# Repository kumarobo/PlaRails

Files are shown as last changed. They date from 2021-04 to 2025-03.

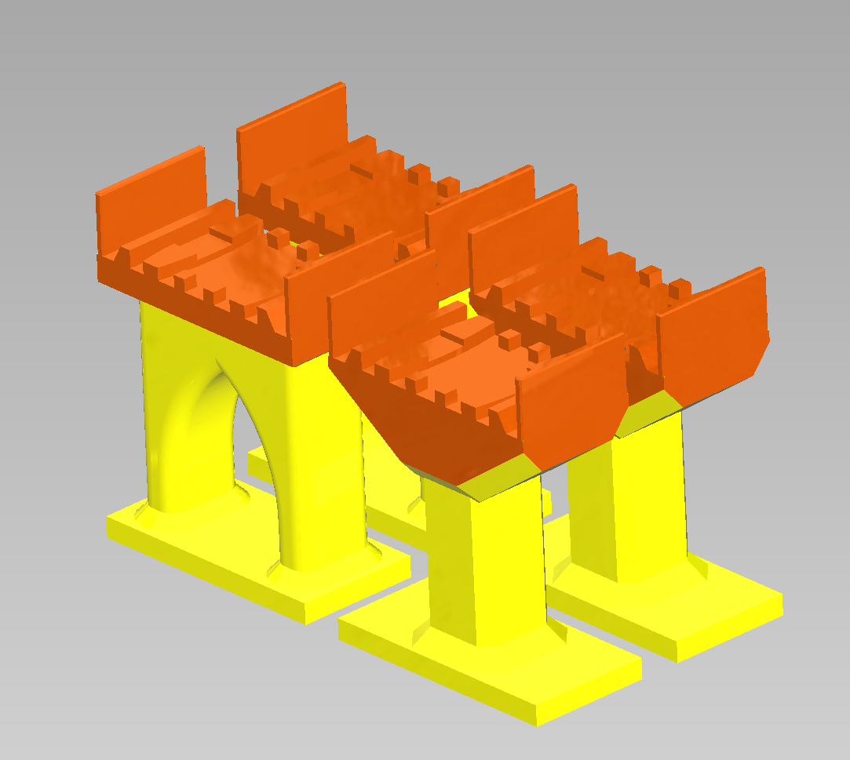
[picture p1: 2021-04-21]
ViaductPillar/vdpillar_printasm.png

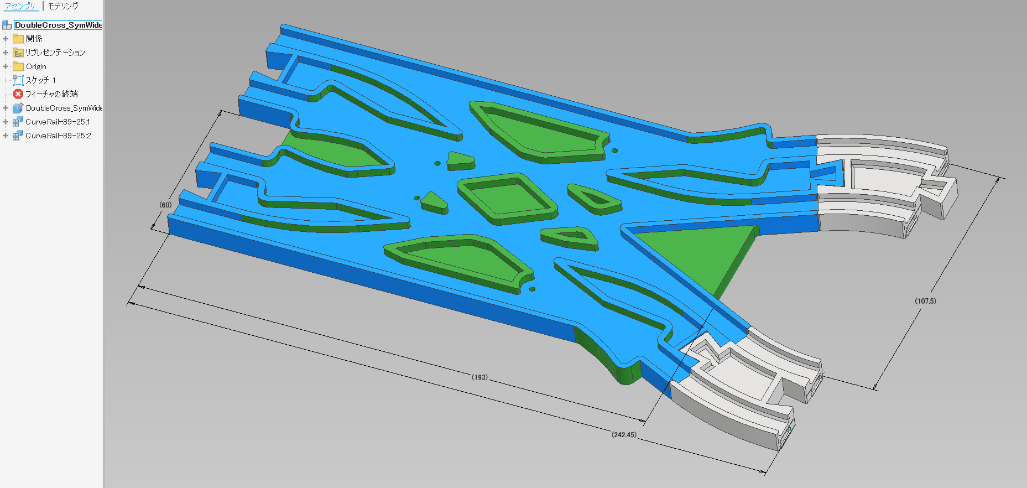
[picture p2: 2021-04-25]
DoubleCross/DoubleCross_SymWiden_testasm.png

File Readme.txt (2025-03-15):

プラレール　レール類設計データセット
熊谷正朗

０．はじめに

　この設計データはプラレールの特殊なポイントおよび高架橋線路を構成するための３次元設計データです。ふとしたきっかけ（忘れた；親戚からお下がりがたくさん届いて、子供らのレールレイアウトのバリエーションが増えたのが主因だと思う）から、突然試作を始めたものです。Twitterで関心を頂いたこと、および、形状構成の事例としての観点から、その設計データを公開することとしました。

１．本データの使用上の注意（ライセンス的）

・まず第一にプラレールは株式会社タカラトミーの登録商標であり、同社の製品です。それゆえ本データの使用の前提には、同社の制約があり、同社が禁じたことは禁じられます。
・本データはas isで提供するものであって、サポートは保障しません。
・本データの利用は、利用者の責任によるものとします。本データの利用に伴うトラブルは利用者で解決し、熊谷は関与しません（成形品の角によるけがや法的問題など）。
・本データの直接的な利用（プリンタによる成形出力）は個人の責任の範囲とし、個人、仲間内の範囲を超えての頒布（販売）は禁じます。ただし、タカラトミー社から正式になんらかの許可を得た場合などはその限りではなく、その場合は確認の連絡を下さい。
・本データのアイデア的な再利用（設計データや寸法を直接的には利用しない）については、利用者に一任します。引用などの明記も不要です。ただし、熊谷まで責任、問い合わせ等が及ばないものとします。
・本データの学修・教育的な利用についても、個人、あるいは学校・団体などの範囲で、利用の責任者が管理できる範囲で利用者に一任します。

※平たく言えば、「手元のデータを公開します。好きにしてかまいませんが、タカラトミー社と熊谷に迷惑が及ばないようにしてください」

２．データの説明
２．１　データの説明

・本設計データは Autodesk社の3DCAD Inventor 2021～2025 Professional (教育向け)で設計されています。同ソフトをインストールしてあれば、そのまま開け、寸法調整、加工等ができると期待されます。設計時のバージョンより古いと開けず、より新しいと変換時に一部ファイルの関係性が崩れる可能性があります。Fusion360ではインポートできるようですが、(関係は深いとはいえ)Inventorの機能を様々につかっているため、どの程度再現できるかは不明です。なお、Inventor(教育向け)は学校関係者は無償で利用できる場合があります。詳しくは同社サイトをご覧下さい。
・3Dプリンタ等用のSTLファイルが用意されている場合があります。これらは主に当方で出力することを念頭にしており、XYZプリンティング社 daVinci Super・ABS樹脂で出力を確認しています(成型誤差は0.1mm程度)。経験からすると、daVinci Pro 1.0でも同等の形状精度が得られると考えられますが、主にポイント類は長さが200mmを超えているため、斜めにおいても入らない場合があります。プリンタの成型精度の誤差については、以下のように調整用のパラメータがあります。
・一部、BambuLab P1Sで出力しています。寸法、形状性能的に、このサイトのレールを印刷するのにベストな機体の一つです（ついに家にもプリンタ置いてしまった）。一部、以前のデータを出力して寸法調整は不要なことを確認しています。
・後のものではSTEP(stp)ファイルが主になっていますが、GitHubのプレビューで形状が確認できるようにSTLも出しています。
・レールの基本長 L=215mm および ジョイント部の寸法、レール断面形状は、家にあったレールから適宜実寸していますが、製品でも寸法にあるていどのばらつきがありました。調整する場合の調整箇所は後述します。
・出力例、組み立て例、設計の解説は
　　　https://togetter.com/li/1682126
　にまとめてあります。

２．２　設計方針とファイルの命名規則
・ある程度ファイルの共通性再利用性を考慮した構成。
・iPart, テーブルを利用した設計
・ファイル拡張子等
　　・ .ipt ：Inventorパーツファイル
　　・ .iam ：Inventorアセンブリファイル
　　・ .stl ：プリンタ用STLファイル（GitHubでプレビュー可能）
　　　　　　　基本的に、同名のiam(優先)もしくはiptファイルから出力
　　・ .stp ：プリンタ用STEPファイル
　　・ _C 　：アセンブリファイルの簡略化のためのシュリンクラップ、
　　　　　　　派生のファイル。
　　・ _S 　：プリント用のサポート材の設計ファイル
　　　　　　　（_Sと_Sなしをアセンブルする場合、_Sに本来の出力対象も
　　　　　　　　含んでいて、これをプリントすれば良い場合の両者がある）
　　・ _MIR ：ミラー（鏡像）の派生ファイル
　　・ printasm ：複数部品をまとめて印刷するためなどのアセンブリ
　　・ testprint, testasm：組み立て試験や印刷試験用のファイル
　　　　　　　　（たとえばポイントのバーの動作参考用、
　　　　　　　　　印刷する前のイメージ確認）
　　・ .ipt, .iam と同名のフォルダ：iPartなどの中間ファイル置き場
　　　　　　　Inventorで自動生成されるので直接は触らない
　　　　　　　（どこかのアセンブリなどで使ったときにテーブルで指定
　　　　　　　　したパラメータでインスタンスができる感じ）
　　・ .png ：参考までに形状を画像で保存したもの。
　　　　　　　_Table.png はiPartのテーブル（ファイル名と寸法の対応）

・基本形式
　　１．機能を得るための形状設計（ポイント形状等）
　　　　　※フォルダ名と同名の iptファイル
　　２．それを分割、ミラー
　　３．レールのジョイント部とともにアセンブル
　　４．継ぎ目消しのため、シュリンクラップして単一形状化
　　５．パーツによってはサポート材の設計追加
　　６．STL出力
　ので、STLファイルと同名のiam (なければipt)から順次、要素を
　たどるとわかりやすい。

・出力の想定
　　・FDM形式の３Ｄプリンタでの出力を想定して調整。
　　　　スライス0.2mm、線幅0.4mmで調整
　　・プリンタ側（スライサ側）のサポートは使用しないことを前提とし、
　　　必要なら設計側でサポート材も設計に入れる
　　　※サポート材の除去の手間など
　　　※部品の下部の斜め面はサポート不要にするため
　　・XYZPrinting社 daVinci superで検証。
　　　一部は daVinci Pro 1.0で出力。
　　・RealRailsはBambuLab P1S＋eSun PLA+で出力検証

３．現時点で含まれている設計

３．１　概要

・特殊長直線、特殊曲率カーブ
・片渡り、単線複線ポイント、Ｓ字カーブ
　および、高架橋側壁オプション
　　　※片渡りからの派生品
・ダブルクロス（シザースクロス）
　　　※複線レール幅、レール超
　　　※ななめに分岐する特殊形を含む
・引き上げ線ポイント
　　　※駅間隔で２：３の線路

・高架橋　橋脚
・単純スロープ（地上から橋脚１段分まで）
・ユニット式高架橋橋脚およびスロープユニット
・リアルクラスに適したリアルな分岐

３．２　説明

●基本ファイル
・root/PlaRails.ipj
　　Inventorのプロジェクトファイル
・root/GlobalParameter.ipt
　　設計全体に関わるパラメータを含む（後述）
　　多くの設計ファイルは直接的、間接的にこのファイルからパラメータ参照している。
・root/RailJoint(Male, Female)(_filled).ipt
　　連結部の形状のファイル。
　　カーブ以外の形状はこれを部品として組み込んで使用している。
　　レールは表面のみであるが、橋脚にはめ込む凹部構造が裏にあり、
　　サポート構造を合わせてプリントするので、あとでラジペンなどでむしる。
　　_filledはこの構造がなく、埋まっている。
・root/RailUnitBase.ipt
　　連結部の元ファイル。ここから一方を消して、上記連結形状になる。
　　そのため、修正するのであれば、このファイル。寸法はGlobalParameterで
　　規定しているものが多い。

・Common/RailJointRS.ipt
　　レールのジョイント部分の形状を定義したファイル（新版）
　　レールの端が浮かなくするためのタブがあるものがあるが、それはあとで切り捨てる。

●特殊長直線 StraightRail/
・StraightRail_i.iam, _C.ipt
　　連結部を引き延ばす方法で直線レールにしている。
　　iPart テーブルで寸法可変。
　　_i でテーブルを選んで、_CからSTLを出力。
　　M, Fはオスメス形状、数値は長さ。

●特殊曲線 CurveRail/
・CurveRail.ipt
　　表裏が欲しいために特殊な構造。
　　XYZPrintの「サポート：底辺」付けたときのブロック部がある。
　　iPartのテーブルで半径と中心角を指定できる。
　　STLファイルの寸法は、半径-中心角、215halfは215/2。

●ダブルクロス・シザースクロス　DoubleCross/
・はじまりのレール。
　それゆえ、設計は一番汚いので、整理された設計は 片渡りシリーズ Crossover参照
・ストレートなダブルクロスと、渡り線をそのまま直進する形式の
　ポイントを構成可能な派生品を組み合わせでつくる。

・DoubleCross.ipt
　ベースとなる設計。ここで線形をすべて決めている。
　直進型の1/4のパーツと、斜め型の1/4のパーツをiPartで生成している。
　※まず両者を含む形を作り、不要部をマスクして、マスクのオンオフで選択。
・DoubleCross_Straight.iam / _C.ipt
　一般的な複線の直進レール間のダブルクロス。
・DoubleCrossBar.ipt / _MIR.ipt / Pin.ipt / Bar_printasm.iam
　ポイントのトングにあたるバーの設計データ。
　左右はあるが、直進・斜めとも同じバーを使うように設計してある。
　Pinはバーの動作軸部品。
　printasmは使いそうな部品のまとめ印刷セット。
・DoubleCross_Rturn
　「仙台市地下鉄東西線八木山動物公園駅型ダブルクロス」
　駅のホームに行くところが斜め分岐。
　testasmに、特殊長直線・カーブとの組み合わせ図。
・DoubleCross_SymWiden
　Rturnを両側にして、かつ、特殊カーブと組み合わせて駅幅＝(1/2)Lにする例。
　※この設計法の特徴例示でプリント試作はしてない
・DoubleCross_DoubleSlant, DoubleCross_DoubleSlip
　どちらもダブルスリップ的形状。png参照。
　※この設計法の特徴例示でプリント試作はしてない

・DoubleCrossRail.iam / _C.ipt / TestAsm
　上記レール群の試作検討用。

・組み立て方：
　　Bar(_MIR)にBarPinを入れて、レール部分の穴に固定する。
　　使用ネジ：M2ナット、M2x8mmネジ
　　ネジを入れる前に、BarとPinが抵抗なく回るようにBarの穴を調整。
　　BarPinおよびレール側の穴をネジがスムーズに通る程度に調整。
　　※5mmリーマ加工／2mmリーマ加工

●片渡り クロスオーバー　シングルクロス　および高架化側壁　CrossOver/
・片渡りポイント
　および、このデータから派生した、単線複線ポイント　複線Ｓ字渡りカーブ
・レール設計としては最終で、設計方針は一番洗練されている。

・SingleCross.ipt
　基本の設計ファイル。形状はすべてここで規定。
　ベースとなるのは片渡りの半分を含む、単線複線型レール。

・SingleCross_PointHalf.ipt / _MIR.ipt
　SingleCrossのポイント側半分、およびそのミラー。
・SingleCross_CurveHalf.ipt / _MIR.ipt
　SingleCrossのカーブレール側半分、およびそのミラー。

・SingleCrossIA.iam / _C.ipt / _C_MIR.ipt
　PointHalf, CurveHalfを組み合わせて、iAssemblyによって
　　・片渡り、シングルクロス
　　・Ｓ字カーブ
　　・単線複線ポイント（ジョイントのオスメスで２種）
　をつくる。
　STLの生成には、まずSingleCrossIAのテーブルで一種を選択し、
　それを反映した _C.ipt もしくは _C_MIR.iptからSTLを出力する。
・SingleCrossBar.ipt / _MIR.ipt
　ポイントのトングに当たるバー。
　ピンはDoubleCrossなどのものを流用。

・SingleCrossIA_Cross(_MIR).stl
　片渡りポイント STL
・SingleCrossIA_Curve(_MIR).stl
　Ｓ字渡り STL
・SingleCrossIA_PointA(_MIR).stl
　単線複線ポイントA型 STL

・SingleCrossIA_MIR.iam
　IA.iamのミラーにあたるアセンブリ。STLはIA.iamだけでつくれるが、
　別のアセンブリに読み込みたい場合用。

・ポイントの組み立て方はDoubleCrossと同じ。

・RailVCoverST.ipt ST_S.ipt
　直線レールを高架橋レール相当にするための外付けオプション側壁。
　ST.iptが必要な形状を規定し、ST_S.iptではプリントするための
　自前設計のサポート材を含んだ形状。
　ST.iptのfxのLengthパラメータで全長が指定できる。
　　（標準はレール長－連結部長さ＝橋脚の幅、高架レールと同じ形状）
　はめ込んだ後、裏面のフックに必要なら適宜輪ゴムなど。

・RailVCoverCV.ipt CV_S.ipt
　同じく、単線複線ポイントのカーブ側の側壁。
　ポイントの凸部を収納する構造。
　※Ｓ字渡りにもそのまま使える。
　組み合わせ方はpointtestasm参照。

●引き上げ線ポイント PocketTrackPoint/
・PocketPoint_C.ipt、.stl
　　ポイントレール部分の最終形状。プリント用。
・PocketPoint.ipt
　　ポイントの機能形状部分を規定してあるパーツ。
　　寸法調整などはこのファイルで行う。
・PocketPointBar*.ipt
　　ポイントのトングにあたるバーの形状を規定。
　　BarPinはバーの回転軸にあたるピン
・pp_bar_printasm
　　バー類をまとめてプリントしやすくしたアセンブリ
・組み立て方：
　　BarにBarPinを入れて、レール部分の穴に固定する。
　　使用ネジ：M2ナット、M2x8mmネジ
　　ネジを入れる前に、BarとPinが抵抗なく回るようにBarの穴を調整。
　　BarPinおよびレール側の穴をネジがスムーズに通る程度に調整。
　　※5mmリーマ加工／2mmリーマ加工

●少しおしゃれな高架スロープセット SimpleSlope/
・ユニット式高架橋セットの前段階の試作品
・市販の高架橋直線レールを主に用い、それを乗せる短レール付きの
　橋脚部品の３点セット。
　この３個のセット＋高架直線レール２本の組でしか役に立たない。
・全体で直線レール 2+(3/4)の長さになる
・SlopeProfile.ipt
　　線路の側面の線形の設計。ラインは走行面を基準としている。
　　高架直線レールを斜めに使うことで、水平面内では短くなる(cosθ)
　　影響は、橋脚部品の長さで補填している。
　　基本的に、GlobalParameter由来の数値で設計。
・Slope_LowEnd.ipt / .iam / _C.ipt
　　床面→スロープとなる下部部品。
　　高架レールを接続するとわずかに、高架レールの側壁角が床に当たる。
・Slope_Middle.ipt / .iam / _C.ipt
　　中間部分。高さ的には高架の半分。
・Slope_HighEnd.ipt / .iam / _C.ipt
　　スロープ→水平となる上部部品。高さは高架１段分。
・Slope_testasm.iam
　　直線レールと組み合わせた組み立て図。

※試作品なので、オスメスは１方向のみ
※iamのRailJointMale/Femaleをコンポーネント変更すればよい

●ユニット式高架橋 ViaductPillarUnit/
・標準の高架橋の高さ(以下、H)の1/2を基準として、高架橋を構成するユニット。
・高架橋の脚部と、1/4長レールを含む高架橋のユニットからなり、標準市販品の高架レールと組み合わせて使う。
・FDM式プリンタでプリントすることを想定して、サポート材を最初から適した形で設計に組み入れてある。
・脚部ユニットは角が鋭く、ある程度丸めた方が良いが、斜め45度の面はFDMプリントのことを考慮した形なので、修正は要注意。

・ViaductPillarUnit.ipt
　　以下の高架ユニットの基本形状の設計ファイル。
　　これを一度分割して、適宜組み合わせることで、必要な形状をつくる。
　　意匠の修正はこのファイルで行えば良い。
・ViaductPillarUnit_S.ipt
　　高架ユニットのプリント用サポート材。
　　それらしい形を作り、最後の「シェル」で薄肉化している。
・ViaductPillarUnit.iam　_C.ipt
　　無印と_Sを組み合わせたもの。

・VPU_EdgeBottom.ipt, VPU_edgeTop.ipt, VPU_MiddleBottom.ipt, VPU_MiddleTop.ipt
　　ViaductPillarUnit.iptを、端部・中間部を下部・上部に分割した物。
　　これを組み合わせると単一線路の複数スパンの高架がつくれる。
・VPU_SupportSingle.ipt
　　ViaductPillarUnit_S.iptのサポートの端部を切り出してミラーして、１区間ようのサポート材としたもの。

・ViaductPillarUnitIC.ipt, IC_S.ipt
　　複線にするための、幅方向の連結ユニットおよびそのサポート材。
・VPU_IC_Bottom, Top, SingleSupport.ipt
　　下部、上部、サポート材

・ViaductPillar_SingleSpan.iam _C.ipt
　　脚ユニット：長さ1/4長、幅１線路用、高さ(1/2)H・1H
　　テーブルでサポートの有無も含めて、切り替えて、_Cから、STL出力。
・ViaductPillar_SingleSpan_C_1u.stl, 05u.stl
　　STLにしたファイル。

・ViaductPillar_SigleSpan_Doublelane.iam, _C.ipt
　　長さ1/4長、複線用の脚ユニット。
　　_C_05u.stl は(1/2)HのSTL（サポート込み）

・Viaduct_HorizontalSingle.ipt, .iam, _C.ipt
　　(1/4)Lの直線レール、側壁を含む、高架橋ユニット。高架直線・曲線レールと接続できる。
　　基本設計は下記VPUSlopeと共通。

●ユニット式高架橋 スロープユニットセット VPUSlope/
・ユニット式高架橋の上部構造として、水平→登り傾斜、傾斜延長、登り傾斜→水平、の３ユニット。
・傾斜の斜度などはSimpleSlopeと互換（SimpleSlopeがVPUSlopeのアイデア検証試作）
・高架直線レールと組み合わせた１スパンで(1/2)H上る

・Slope_Profile.ipt
　　傾斜および水平との遷移の形状の側面図。各ファイルの形状の基準。

・Slope_LowEnd.ipt, .iam, _C.ipt
　　床面→登り傾斜のユニット。
　　.ipt は基本構造、.iamでレール端部と高架ユニットの脚接続部を組み付けて、_C.iptでラップしてSTL出力。
　　基本的に上り部は、間に挟む高架直線レールが、上がオス(凸側)、下がメス(凹側)になるようにしている。
　　全体の極性は、傾斜の出入り部で変えられるようにしてあり、.iamにFM型(水平側メス)とMM型(水平側オス)がある。
　　それぞれSTLとpngがある。

・Slope_LowEndHi.ipt, .iam, _C.ipt
　　高架水平→上り傾斜のユニット。
　　LowEndと同様。

・Slope_Middle.ipt, .iam, _C.ipt
　　上り傾斜の中間ユニット。１個入れるごとに全体で(1/2)H高くなる。
　　登り部の極性は固定のため、このユニットは１種のみ。

・Slope_HighEnd.ipt, .iam, _C.ipt
　　上り傾斜→高架水平のユニット。
　　同様に、FF型(水平側メス)とFM型(水平側オス)がある。

・testasm.iam testasm2.iam
　　組み立て例

●ダブルスリップポイント DoubleSlip/
・基本構成 直線の半分 (1/2)L で、45度に交差するダブルスリップポイントレール。
・２本のバーの可動で直進第一方向、直進第２方向、および分岐ができる。
　　※バーの位置は３カ所、中間点はラッチする
・ポイント内にバーの連動機構を持っていて、バーは対称に動作する。
・組み立てには、M2x8のナベネジ(x9くらいほしい) ２本、M2x5の皿ネジ１本、M2ナット３個とABS接着が必要。
・2021 6/13 改訂：
　　当初は斜め渡りするために、長さを√2倍したHS型を用意していたが、左右の必要性
　　などを考慮して、ポイントそのものは H (＝1/2L）型のみとし、斜め渡りに対応する
　　長さの短いレールと、ダブルクロスにするためのクロスのレールを別途組み合わせる
　　こととした。
　　そのほか、細部の寸法の調整。

・組み立て手順
　　・レール中央部にGearCenterをはめ、回転したときに「ほどほどの抵抗」があり、中央でラッチするように調整する。
　　　調整は、たとえば、GearCenterの内側をカッターなどで少し削って整えるなど
　　　（プリント時に面を後退させすぎるとそもそもかすらない可能性あり）
　　　中央より時計回りは少し緩めに、反時計回りをそれより少し強めに、がよい。
　　・M2のナットをしっかり押し込んでおく、必要なら一度ネジを入れてしっかり締める。
　　・GearBarBaseを左右のポストにさして滑らかに回るように。
　　・DSHR_BarCoverを重ねてネジで締められること、GearCenterない場合にほどほど緩く回ることを確認。
　　　※ここがわりと微妙、ネジの長さがギリギリで。BarCover裏を削る必要があるかもしれない
　　・GearCenterを入れて中央にラッチし、GearBarBaseにうっすらある直線の模様が、
　　　バーが分岐するのに適した方向、をほぼ向くように、噛み合わせてはめる。
　　　※直線の模様は単なる今後の作業の目安で、必須ではない
　　・GearBarBaseに、DoubleSlipHR_BarをABS接着剤で接着する。
　　　このとき、ギア部のガタは、GearBarBaseを時計回りにしっかり回して寄せておく。
　　　※当然のように周囲の可動部にも付くと思うので、位置決めしたら、BaseとBarの組をすぐに外した方がよい。
　　・接着剤が固まった後、穴の内部などを調整の上、組み立て。
　　　問題なければ、一方を動かすともう一方が対称に動く。
　　　※Coverをつけないと中央の穴に引っかかる場合があるので注意。
　　・GearCenterCoverを皿ビスで留める。
・組み立て（簡易）：
　　・特に連動とか不要なら、部品を一通り組み立てて、「接着」せずに、単にバーだけ渋く回るように調整する。

・DoubleSlipHR.ipt, .iam, _C.ipt, .stl
　　ポイント設計本体(ipt, 半分の形状)、iptと連結部を組み立てたもの(.iam, _C.ipt)。
　　.iptのパラメータ、テーブルにより、直進部分の長さを変えられる。
　　　　StraightLength/2 ＝ (1/2)L, *sqrt(2) ＝渡りにする長さ
　　　　接尾 _Hは(1/2)Lを、_HSは(1/2)L*sqrt(2)を設定してある。
　　　　※変更は .iamで使っている .iptのテーブル部

・DoubleSlipHR_asmtest.iam
　　ポイント機構の組み立て図。
　　※各部品の機械的な連動までは入れていない

・DoubleSlipHR_printasm.iam, .stl (printbase.ipt含む)
　　レール本体以外の部品類を印刷するためにまとめたもの。
　　レール本体にブリムをつけて一緒に印刷することを想定して、ブリムよけのガードが含まれる。

・DoubleSlipHR_Bar.ipt, DSHR_BarCover.ipt
　　ポイントのバー部品。および、バーを上から押さえるカバー(一部レール要素)。
・GearBarBase(Gear20含む), GearCenter(Gear30含む), GearCenterCover.ipt
　　バーを動かすギア部品(一部走行面を含む)、中央のギア(バーの位置決めをするラッチ構造を持つ)、
　　同カバー(分岐時に走行する面)。

・CrossRail.ipt, .iam, _C, _C_DSS.stl
　　直角交差のレール。
　　DoubleSlipHR_C_H_Hと組み合わせると、駅幅のダブルクロスポイントができる。
　　交差が小さく、連結部が干渉するので、削る小細工をしている。

・/StraightRail/StraightRail_C_DSSMF.stl
　　DoubleSlipHR_C_H_Hと組み合わせると、駅幅の片渡りができる。
　　組み立て例はtogetterなど参照。

・RailJointShortMale/Female(_filled)(_ShortHead).ipt
　　レールの連結部、ただし、root/にあるものに比べて、部品の長さを限界まで短くした。
　　レール側に窪みが必要(DoubleSlipHR.iptの端部参照)
　　_filledは裏面の橋脚にはめる構造を埋めたもの
　　_ShortHeadは上記CrossRailとあわせて、走行面を確保するために先を削った形状。
　　　　（DoubleSlipHRはこの形状）

●Ｓ字シフトレール ShiftRail/
・複線などの線路間隔を変更するための、方向は変わらずに横にシフトするＳ字のレール
・現在のラインナップは、駅複線((1/2)L)を複線レール幅(60mm)と変換するためのレールで、
　その間隔の 1/2, 1/1, 3/2 の３種
　※1/2は２個対象に使うと幅が変換できる、1/1は片方のみ(複線幅広ポイントレールと同型)
　※3/2は複々線から拡げる(3/2, 1/2, 1/2, 3/2と使う)
・レール線形は簡易的なクロソイド曲線
・珍しく「表裏対応」型、FDMプリントのサポートの設計付き。

・ShiftRail.ipt
　　レールの設計本体。
　　作図は1/4のみで、ShiftRail.ipt でレールの1/2部分が完成する。
　　テーブルで寸法を切り替える。
　　パラメータ：
　　　　Length：進行方向の長さ　（線路仕様）
　　　　Shift：遷移幅　（線路仕様）
　　　　MinRadius：最小半径　　（調整項目）
　　　　CLength：曲線区間長さ　（調整項目）
　　　　NSection：クロソイド区間数（固定値）
　　　　CF：クロソイド化フラグ：1でクロソイド、0でただの円弧
　　　　SD：現時点で不要
　　　設定方法：
　　　　・LengthとShiftを欲しいレールの寸法で決定する
　　　　・スケッチ１を見ながら、MinRadiusがなるべく大きくなるように、
　　　　　曲線区間が作図範囲の概ね中央部にくるようにCLengthを調整。

・ShiftRail_TC.ipt, .iam, _C.ipt
　　レール形状に組み立てる。
　　_TCはiPartでなくするための中間派生ファイル、.iamで連結部含めて組み立て、
　　_C.ipt でレール形状は完成。サポート不要なら _CからSTLを出力。

・ShiftRail_S.ipt
　　ShiftRail_C.ipt にFDMプリント用のサポート材を付加。
　　サポートの条件は davinci superで出力するように調整してある。

・ShiftRail_S_*.stl
　　プリント用STL
　　　　12L_HDL12：長さ＝(1/2)L、シフト＝(駅幅(HL)－複線幅(D))×(1/2)
　　　　34L_HDL：　長さ＝(3/4)L、シフト＝(駅幅(HL)－複線幅(D))×(1/1)
　　　　1L_HDL32： 長さ＝(1/1)L、シフト＝(駅幅(HL)－複線幅(D))×(3/2)
　　　※12L_HDL12_C：12L_HDL12 のクロソイドではない円弧版、比較用
　　いずれも、ぎりぎり短くしてあるのでこれ以上短いのは曲率的に難しい

・RailJointDSMale/Female.ipt
　　このレール用の最短連結部パーツ。
　　両面レールに対応した形状。

●リアルなレール分岐 RealRails/
・組立には、Amazon等で売られているインサート ナット2mm外形3mm長さ3mmを使う。
　　※使用したのはuxcell ローレットM2x3, ASIN B0778FB9Y5
　　それ以外を使う場合は圧入穴の微調整がいる。

・RealRailsParameter.ipt
　　形状データは無く、このシリーズで使う数値パラメータを持つ。
・RR_SingleTurnout
　　直線－通常曲線の分岐。
　　_CA, _CBはレールそのものの形状、_SA_C, _SB_Cはプリント用のサポートを含む。
　　（スライスソフト側でサポート設定をしない）
　　Leverはトングレールおよびそのスライド部品。レール本体にバーを差し込んで、
　　対のトングレールを押し込んではめ込むことで一体化させる。
　　トングレールの一方（ボスがあるほう）にはナットをインサート。
　　ネジはM2x8の皿ビスが適合。
・RR_ThreeWay
　　三分岐。
　　添え字は上記の通り、ただし、トングレールは２セット有る。
　　スライド部品を両側から差し込み、数ミリ開いた位置が直進の状態になるので、
　　そこで直進側トング（まっすぐのもの）を挿す。穴が合わない場合はスライダを交換。
・SwitchLeverUnit
　　分岐を駆動するためのレバーユニット。転轍機。
　　上記分岐のスライド部品がでているところに、はめる。
　　下部ケースLowerCaseの四隅の穴の奥にナットをインサートしておく。
　　下部ケースLowerCaseにスライダSliderをはめる(接続ピンが連結形状側)。
　　そこにらせんローラ部品RollerにレバーLeverを圧入したものを付ける。
　　この段階で倒すとスライダが動く。
　　上部ケースをかぶせて、M2x12で締める。
　　レバーを真上付近にすると、スライダ＝分岐器のトングがフリーに動く。
　　そこから両方向に倒すと強制的にスライダが動く。　　

●高架橋脚 ViaductPillar/
・VDPillar_A, VDPillar_B, vppillar_printasm.stl
　　複線レール間隔にも対応した、高架レール向けの橋脚。橋脚に側壁が付いている。
・StandardPillarCover　　※iam, stlは４個まとめて印刷用
　　通常の橋脚に高架レールを乗せて出っ張った部分に、それらしいカバーを付ける。

●「大きな鉄橋」部品 TrussCC/
・思えば、もらってきた鉄橋でこの部品がないから、つくるか、とか
　思ったのがすべての始まりだった気がする。

●その他 Misc/
・AsterMale.ipt / AsterMale_?.stl
　　放射状になるレール。

３．３　設計全体を調整するパラメータ
● /GlobalParameter.ipt
・パラメータ(fxアイコン)に全体の設計を決定づけるパラメータがある。
・各ファイルは直接、間接にこれを引用しているので、ここを書き換えて更新すると、反映される。

●パラメータ一覧
・PrinterOffset
　　プリント時の補正値。プリンタ側で設計値よりも寸法が大きくなる場合
　　（幅が増える、穴が小さくなるなど）にこの数値で寸法を減らせる。
　　ジョイント部の寸法補正などに使われている。
・StraightLength
　　直線レールの長さ。
　　当方の実測で215mmとしてあるが、216mmという説もある。
・RailWidth
　　レール幅
・OuterWall
　　レールの壁部の外側＝レール幅のところ、の壁の幅
・InnerWall
　　同じく、内側の壁の幅
・InsideWidth
　　内側（車輪の走らない領域）の幅
・RailHeight
　　レール全体の厚さ
・RailDepth
　　レール上面から走行面までの深さ、言い換えれば走行面両側の壁の高さ
・ConnectorLength
　　レール連結部部品/RailJointの長さ。
　　この部品を使っているパーツは多いため、変更はかなり要注意。
・JointM?, JointF?
　　レール連結部の凹凸の形状を決める寸法。市販レールでもばらつきがあるため、
　　手元のレールとはまるようにそれらしく拾ってある。
・DoubelWidth
　　複線の間隔。これは60mmでコンセンサスがあるようだ。
・ViaductHeight
　　市販の橋脚の高さ。高架橋シリーズなどの寸法を規定している。
・SupportGap
　　自前のサポート部材があるときに、サポート部材と本体の隙間を規定。
　　FDMプリンタの一層分の隙間がよさそう（当方はすべて0.2mmスライス）。
　　この隙間で結合が弱くなることで、サポート部材をはがせる。
・SupportRib
　　サポート部材の壁の幅。FDMで１列分のフィラメント出力が出る程度。
　　当方は0.4mmのフィラメント出力で少し太めにしてある。（計算誤差対策）

４．まとめ
・とくにまとめはありません（文末表記）

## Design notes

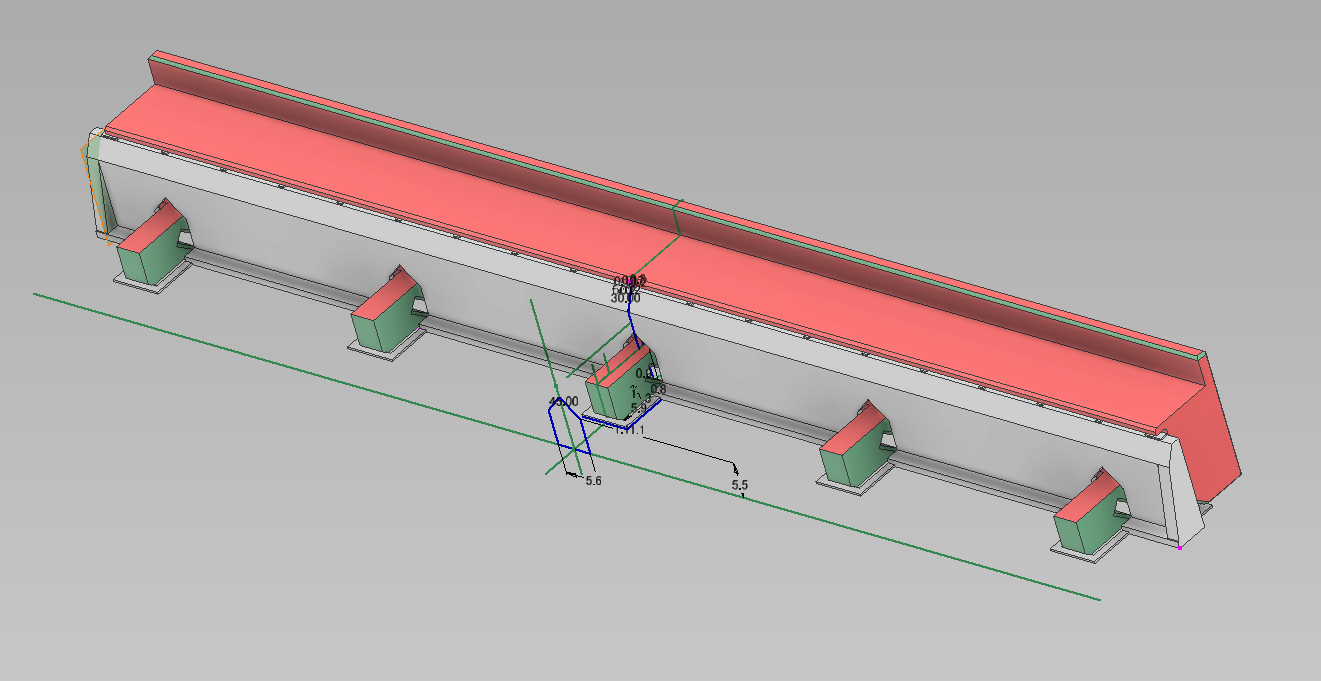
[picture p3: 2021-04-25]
Crossover/RailVCoverST_S.png

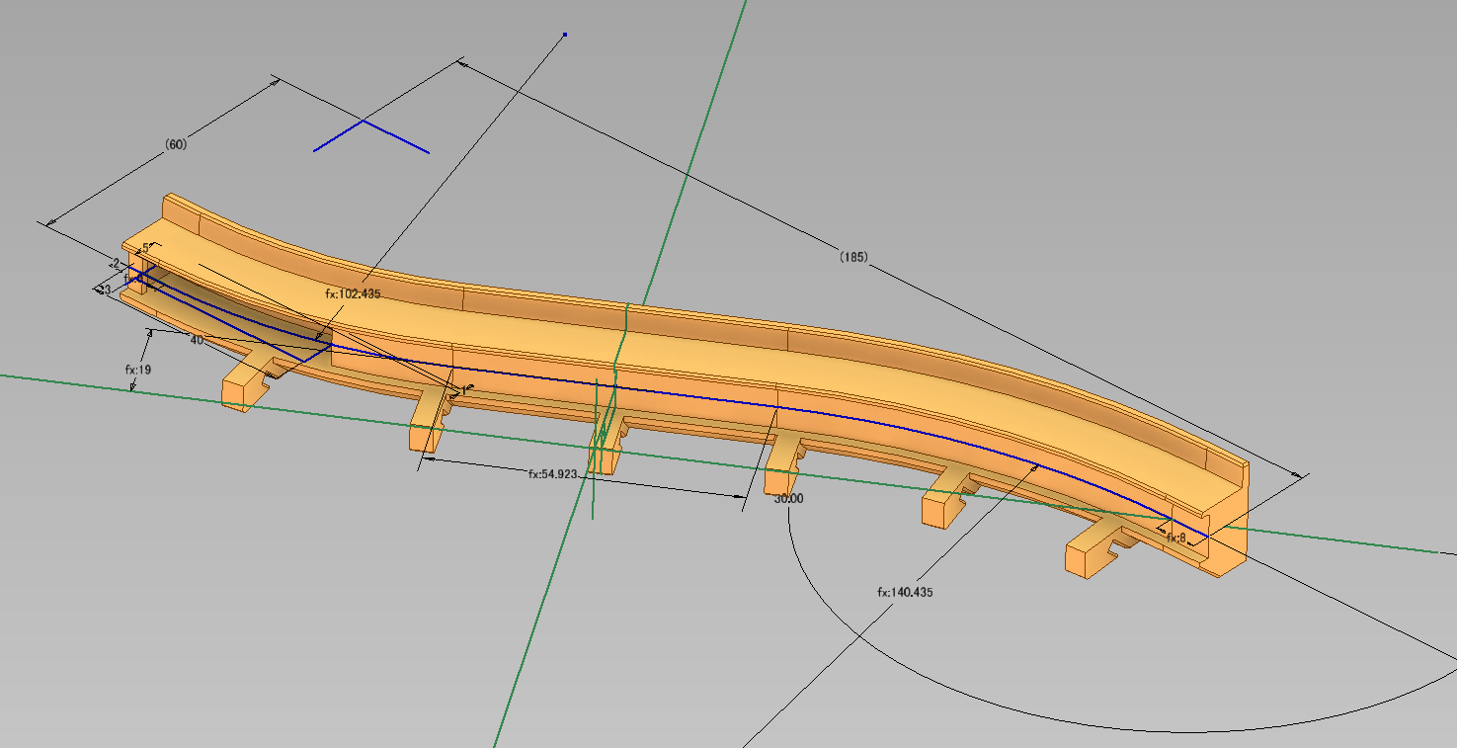
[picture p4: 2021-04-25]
Crossover/RailVCoverCV.png

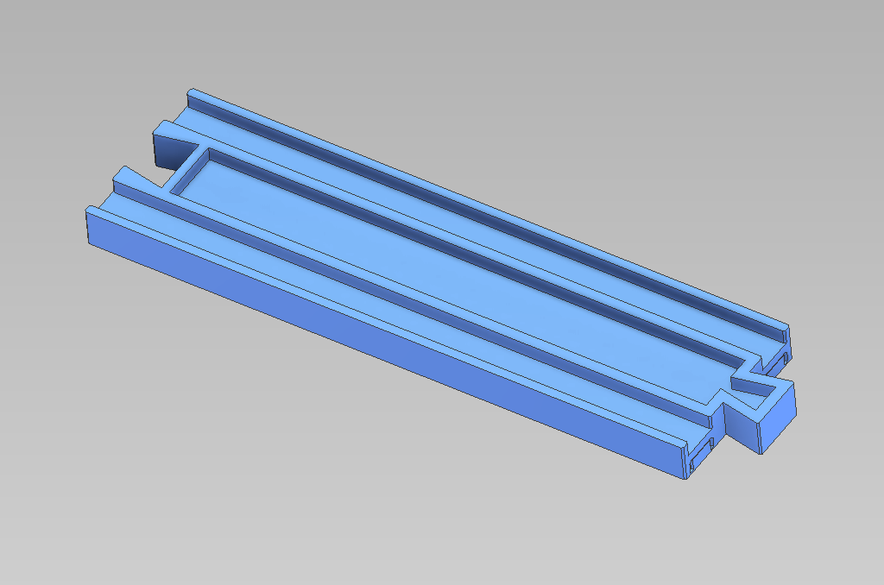
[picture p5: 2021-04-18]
StraightRail/StraightRail_C_134MF.png

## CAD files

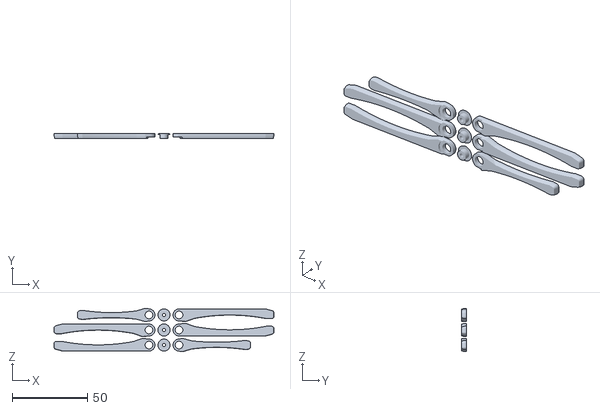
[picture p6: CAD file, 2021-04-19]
PocketTrackPoint/pp_bar_printasm.stl
146.0 x 3.20 x 28.7

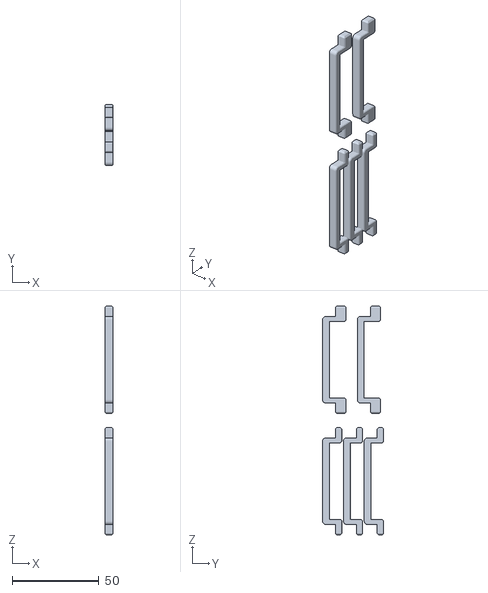
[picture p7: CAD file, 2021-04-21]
TrussCC/TrussCC_printasm.stl
4.80 x 35.1 x 132.0

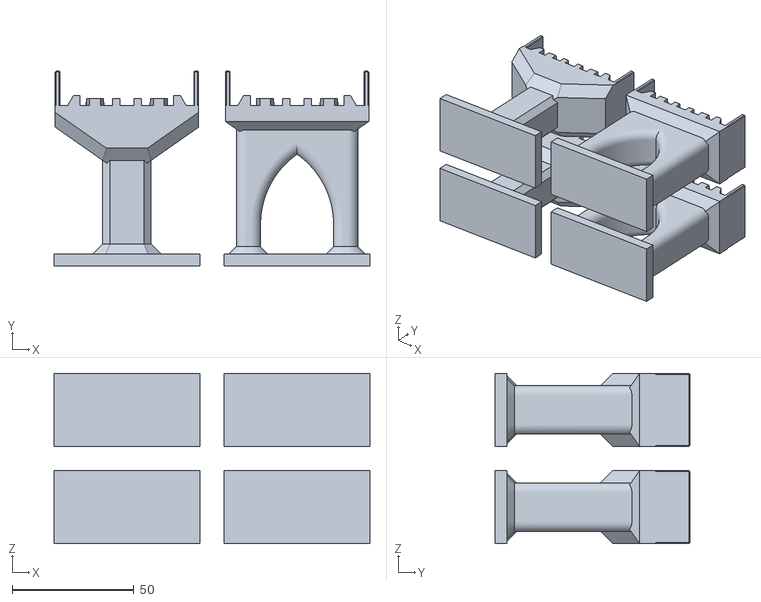
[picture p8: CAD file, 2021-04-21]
ViaductPillar/vdpillar_printasm.stl
130.0 x 80.3 x 70.0

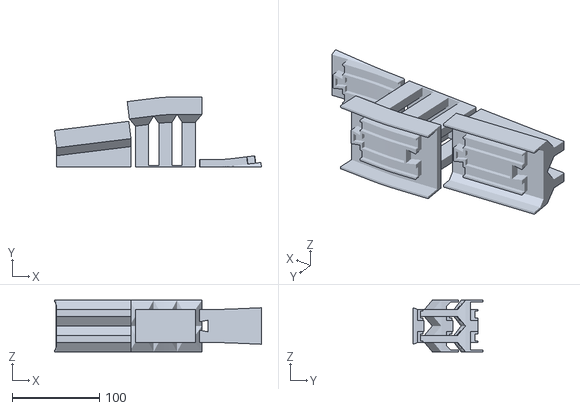
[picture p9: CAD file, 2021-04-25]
SimpleSlope/printasm.stl
236.9 x 80.2 x 59.0

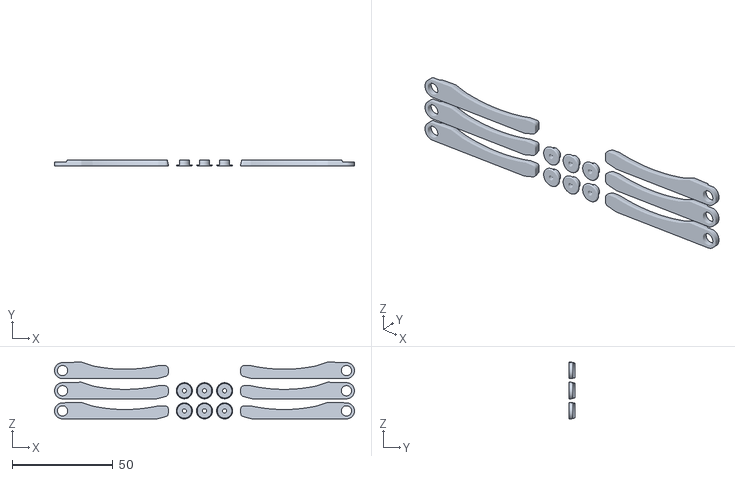
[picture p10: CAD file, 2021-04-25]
DoubleCross/DoubleCross_Bar_printasm.stl
149.0 x 3.20 x 28.2

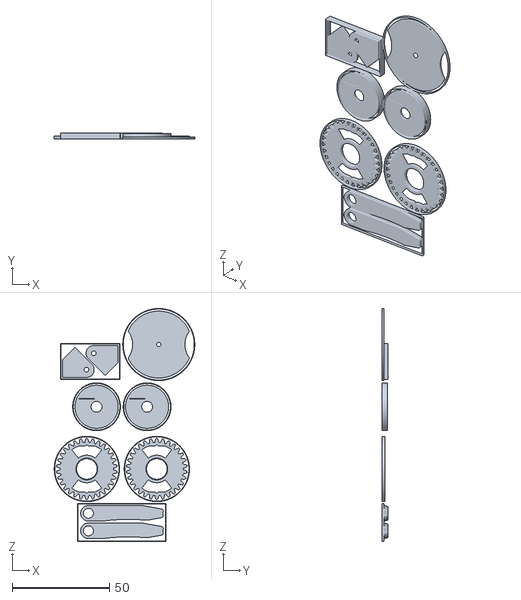
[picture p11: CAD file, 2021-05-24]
DoubleSlip/DoubleSlipHR_printasm.stl
72.3 x 3.20 x 119.8

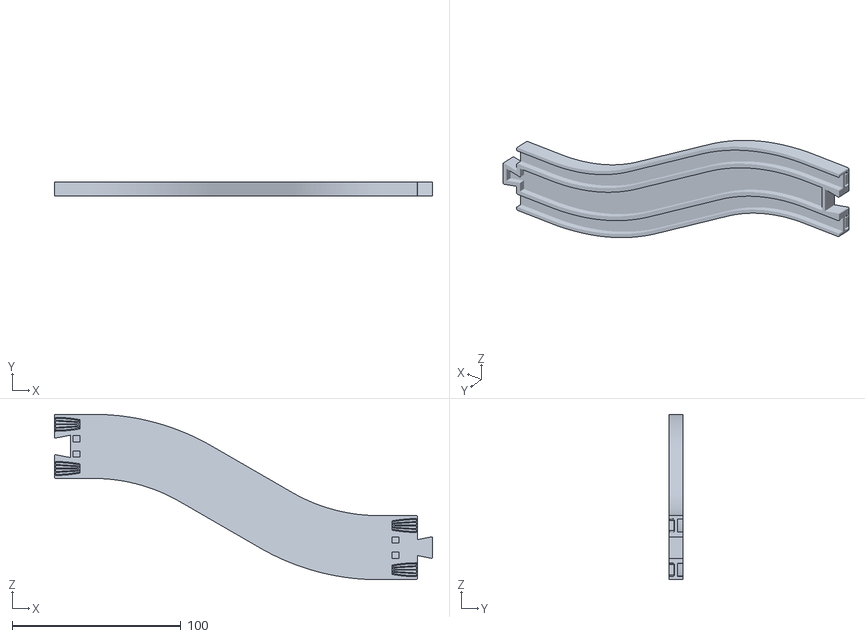
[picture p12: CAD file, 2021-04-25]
Crossover/SingleCrossoverIA_Curve.stl
224.0 x 8.40 x 98.0

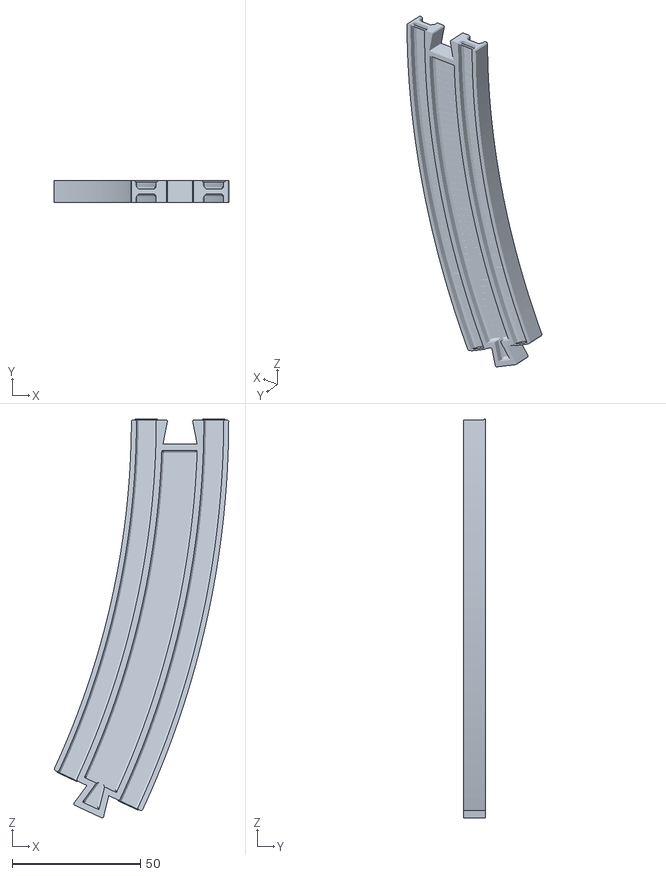
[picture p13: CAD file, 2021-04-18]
CurveRail/CurveRail-342-25.stl
68.1 x 8.40 x 155.6

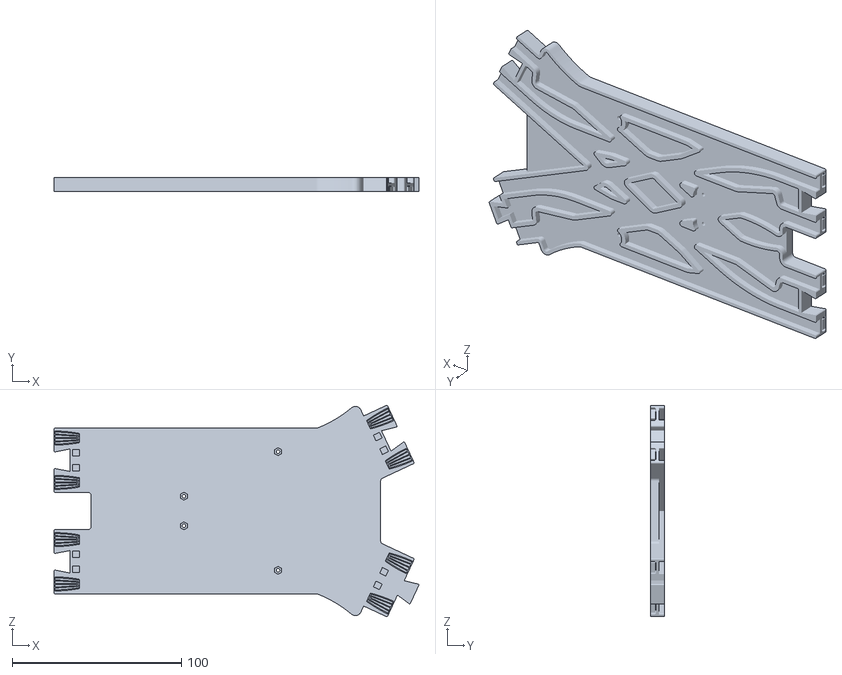
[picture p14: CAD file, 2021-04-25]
DoubleCross/DoubleCross_SymWiden_C.stl
215.7 x 8.40 x 125.0

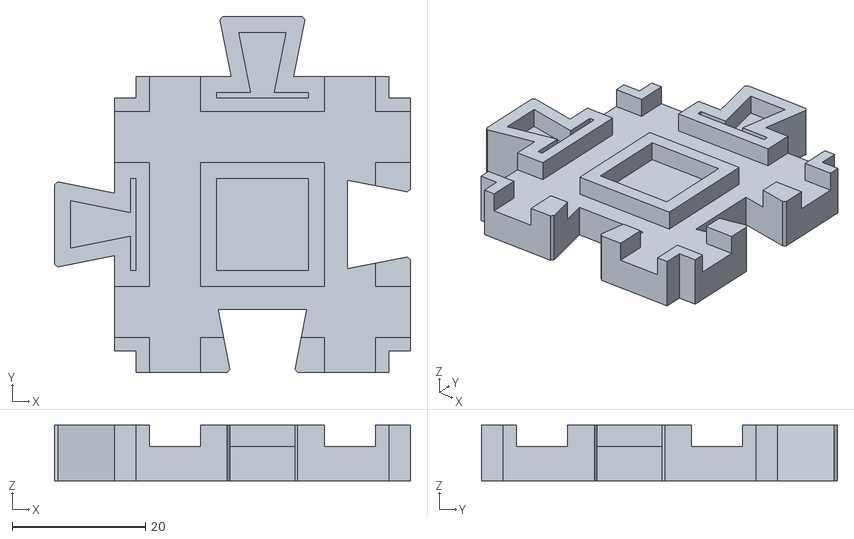
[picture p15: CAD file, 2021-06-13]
DoubleSlip/CrossRail_C_DSS.stl
53.5 x 53.5 x 8.40

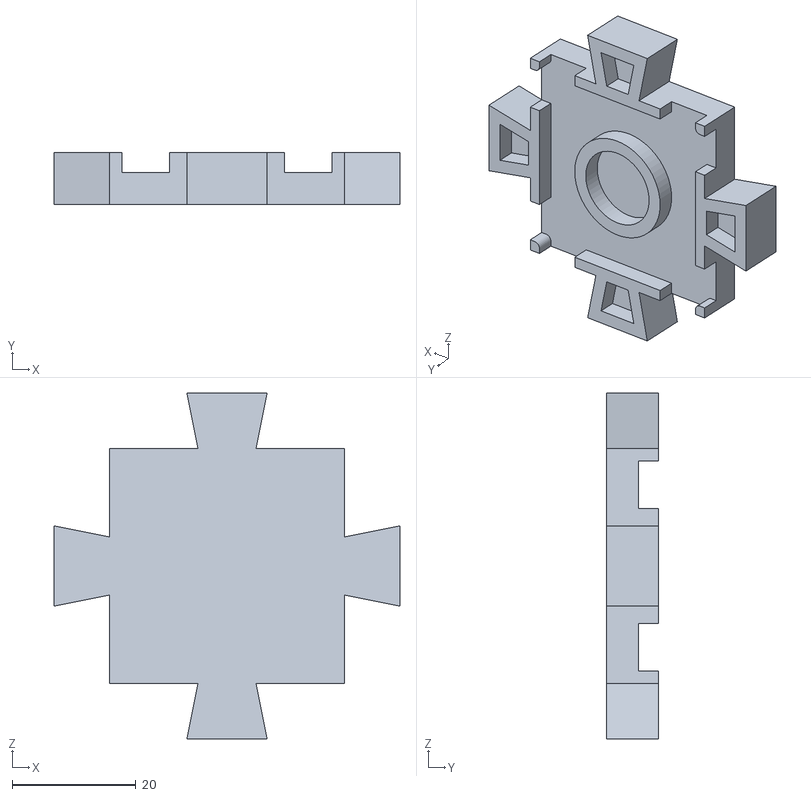
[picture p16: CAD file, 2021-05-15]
Misc/AsterMale_4.stl
56.0 x 8.40 x 56.0

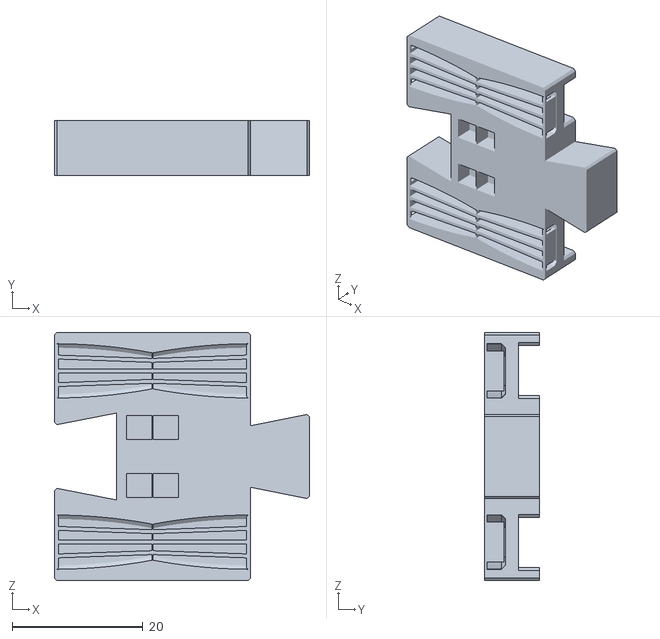
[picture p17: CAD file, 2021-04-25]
RailUnitBase.stl
39.0 x 8.40 x 38.0

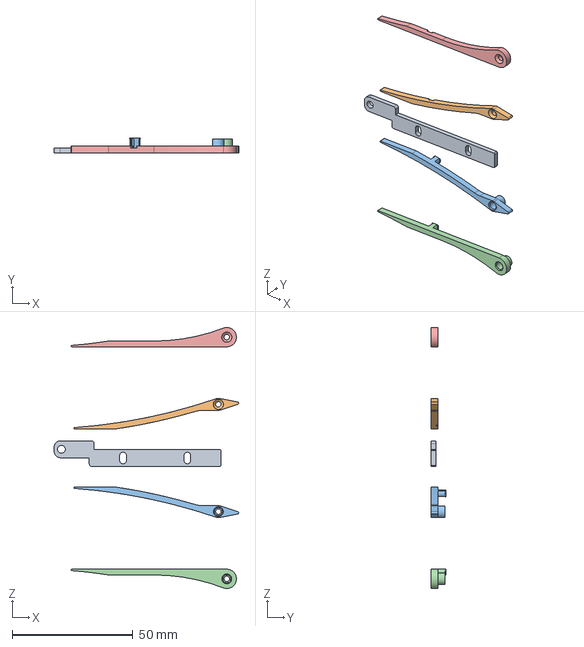
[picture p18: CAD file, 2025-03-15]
RealRails/RR_ThreeWayLever01.stp
76.4 x 6.00 x 108.0 mm

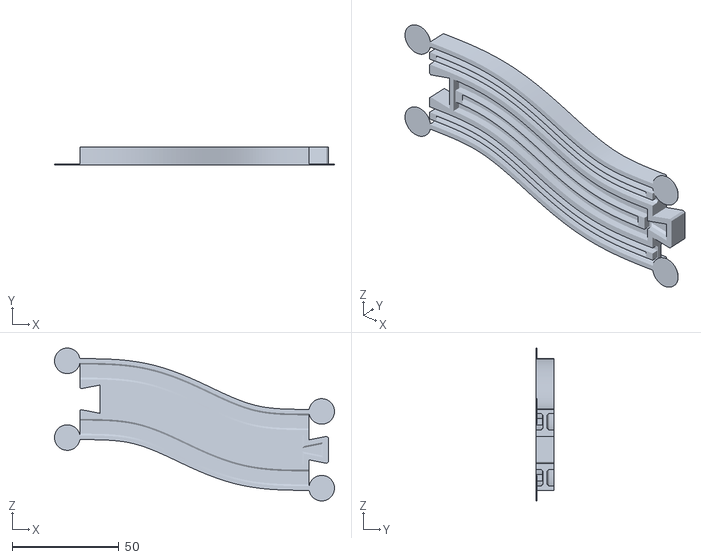
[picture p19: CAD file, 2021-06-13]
ShiftRail/ShiftRail_S_12L_HLD12.stl
131.3 x 8.40 x 71.7

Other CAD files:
StraightRail/StraightRail_C_DSSMF.stl
ViaductPillarUnit/ViaductPillar_SingleSpan_C_05u.stl
VPUSlope/Slope_Middle_C.stl
Crossover/RailVCoverCV_S.stl
Common/RailJointRS.ipt
Common/RailJointRS/FemaleDoubleSide.ipt
Common/RailJointRS/FemaleDoubleSideWT.ipt
Common/RailJointRS/FemaleSingleFilled.ipt
Common/RailJointRS/MaleDoubleSide.ipt
Common/RailJointRS/MaleDoubleSideWT.ipt
Common/RailJointRS/MaleSigleFilled.ipt
Common/RailJointRS/MaleSingleSide.ipt
Common/RailJointRS/NoJoint.ipt
Crossover/RailVCoverCV.ipt
Crossover/RailVCoverCV_S.ipt
Crossover/RailVCoverCV_S_MIR.ipt
Crossover/RailVCoverCV_S_MIR.stl
Crossover/RailVCoverCV_pointtestasm.iam
Crossover/RailVCoverST.ipt
Crossover/RailVCoverST_S.ipt
Crossover/RailVCoverST_S.stl
Crossover/SingleCross.ipt
Crossover/SingleCrossBar.ipt
Crossover/SingleCrossBar.stl
Crossover/SingleCrossBar_MIR.ipt
Crossover/SingleCrossBar_MIR.stl
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

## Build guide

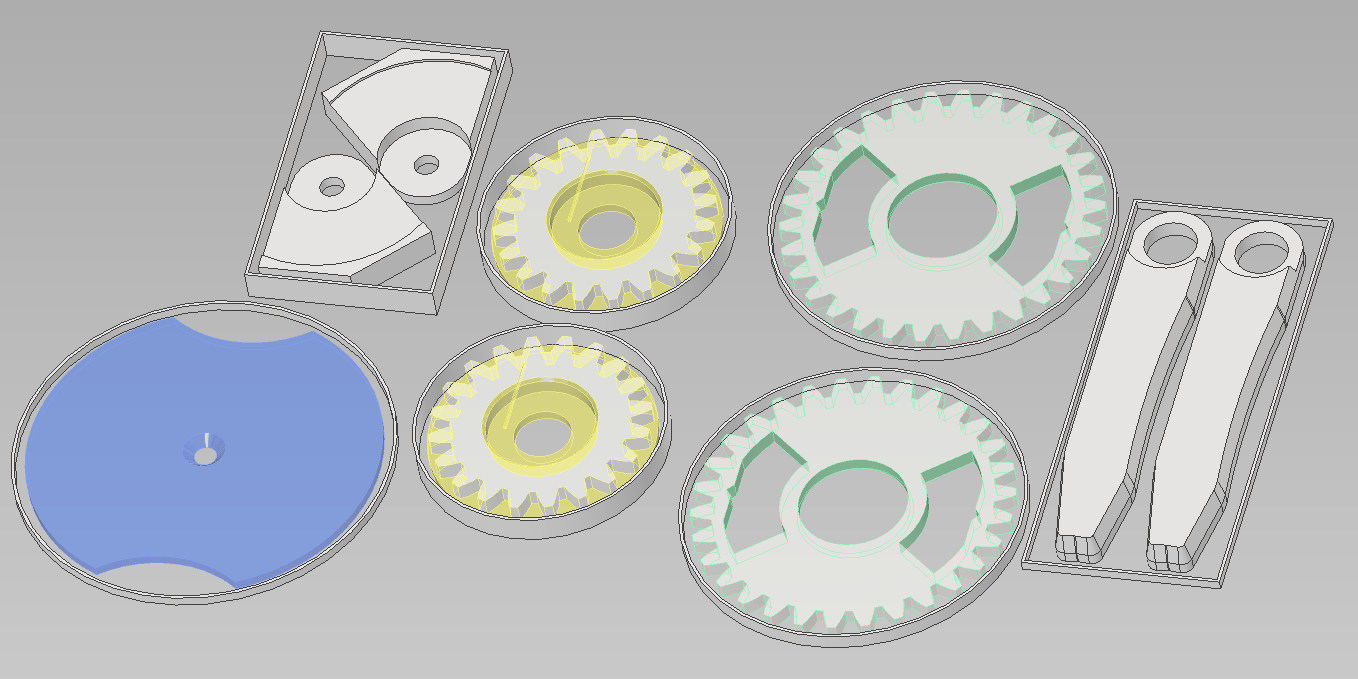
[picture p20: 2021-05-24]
DoubleSlip/DoubleSlipHR_printasm.png

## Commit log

2021-04-18 Partial Upload
    [GlobalParameter.ipt, RailJointFemale.ipt, RailJointFemale_filled.ipt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]
2021-04-18 Add Curve, Straight
    [CurveRail-215-45.stl, CurveRail-215half-45.stl, CurveRail-215half-90.stl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]
2021-04-19 PocketTrackPoint added
    [PocketPoint.iam, PocketPoint.ipt, PocketPointBar1.ipt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]
2021-04-21 Pillar, Truss
    [PillarTopVD.ipt, PocketPoint.ipt, Slope_Middle_C.stl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]
2021-04-25 SimpleSlope added.
    [SlopeProfile.ipt, Slope_HighEnd.iam, Slope_HighEnd.ipt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]
2021-04-25 DoubleCross added
    [DoubleCross-SL_M.ipt, DoubleCross-SL_R.ipt, DoubleCross-ST_M.ipt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]
2021-04-25 Crossover(SingleCross) added
    [RailVCoverCV.ipt, RailVCoverCV_S.ipt, RailVCoverCV_S.stl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]
2021-05-15 ViaductPillarUnit added
    [AsterMale.ipt, AsterMale_4.stl, AsterMale_6.stl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]
2021-05-15 VPUSlope added
    [AsterMale.ipt, SlopeProfile.ipt, Slope_HighEnd.iam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]
2021-05-24 DoubleSlip added
    [DSHR_BarCover.ipt, DoubleSlipHR.iam, DoubleSlipHR.ipt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]
2021-06-13 ShiftRail added
    [RailJointDSFemale.ipt, RailJointDSMale.ipt, ShiftRail.iam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]
2021-06-13 Double Slip Update
    [CrossRail.iam, CrossRail.ipt, CrossRail_C.ipt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]
2025-03-15 RalRails Upload
    [FemaleDoubleSide.ipt, FemaleDoubleSideWT.ipt, FemaleSingleFilled.ipt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]
2025-03-15 RealRails Update
    [RR_SingleTurnout_SB.ipt, RR_SingleTurnout_SB_C.ipt, RR_SingleTurnout_SB_C.stl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]
